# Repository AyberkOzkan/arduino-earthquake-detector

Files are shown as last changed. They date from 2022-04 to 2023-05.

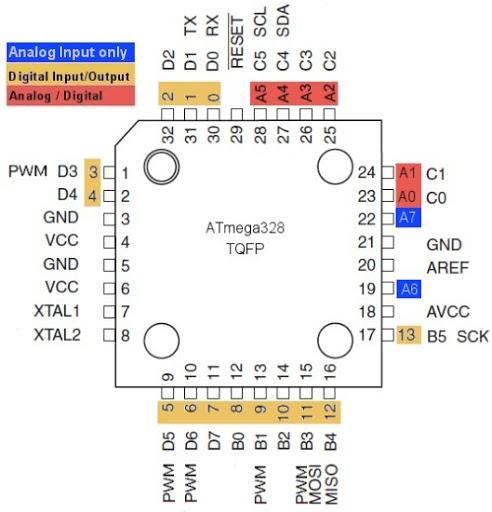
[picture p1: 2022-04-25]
Özel Arduino Nano Tasarımı/Arduino ATmega328 Pinout.jpg

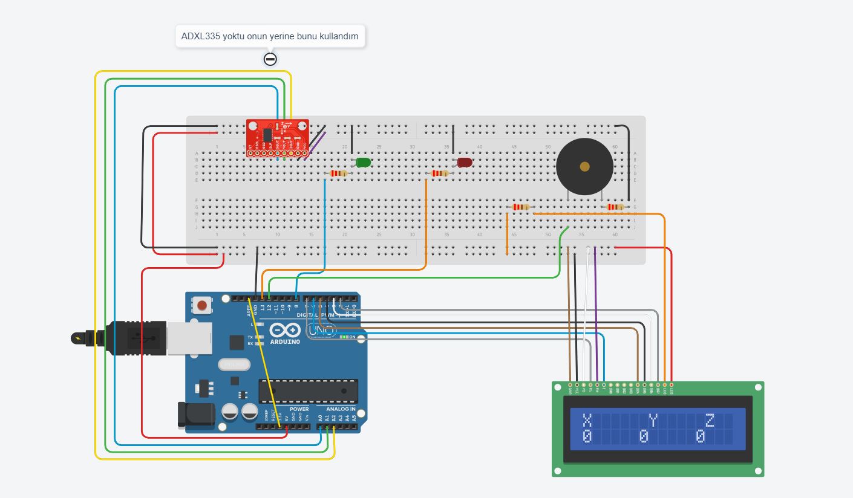
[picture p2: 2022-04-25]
TinkerCad Bağlantı Şeması.JPG

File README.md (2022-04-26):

# Arduino Earthquake Detector

### What I did use?
- Arduino Nano (Personalized and Redesigned) and Arduino UNO
- ADXL335 3 Axis Accelerometer
- 2x16 LCD Display
- Led (Red and Green)
- Resistors
- Buzzer
- Jumper Cables
- Arduino IDE
- Altium Designer
- Processing 3
- Tinkercad

## Tinkercad Connection Diagram


```Bash
The sensitivity was very low when it was first turned on. In order to increase its sensitivity, 
the AREF pin is connected to the 3V3 pin and the analogue inputs are set to 3.3V instead of 5V. 
This made the ADXL335 work more smoothly.
```
## Conclusion and Discussion
> I had the opportunity to test the project with artificial vibrations and real earthquakes and the expected results were obtained. Thanks to its small design, it adapts well to the place where it is intended to be mounted. The fact that this place is the columns of the building will enable the sensor to work more accurately. In addition, with Arduino, we can adjust how natural gas, water or other smart home systems of important systems should behave in case of an earthquake. Vibration waves can be watched and recorded live on Processing with the help of a computer.
> I designed an additional circuit to further increase its sensitivity.
```Bash
The main logic of this circuit was this: to amplify only the useful part of the signal without amplifying harmful noise.
```

>To do this, the instrumental operational amplifier i.e. OPAMP, connected in differential mode, OP07 IC can be used as an example. It can be used in any OPAMP IC. Using the potentiometer, we must set the voltage V2 to be slightly lower than V1 and set the utility signal with a second potentiometer.
>The formula for the amplification coefficient is 
<p align = "center">Vout = (V1-V2) * K<p/>
<p align = "center">K = 1 + 100 / P2 (kOhm)<p/>

> This amplified signal must be connected to the analogue input of an Arduino microcontroller via a 1k resistor. 
> To amplify the ADXL335's three outputs, we will need to use three identical amplifiers for each axis (x, y and z) separately.

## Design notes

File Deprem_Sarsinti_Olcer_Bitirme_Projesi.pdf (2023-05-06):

T.C.

### FIRAT ÜNİVERSİTESİ

### TEKNOLOJİ FAKÜLTESİ

### ELEKTRİK-ELEKTRONİK MÜHENDİSLİĞİ BÖLÜMÜ

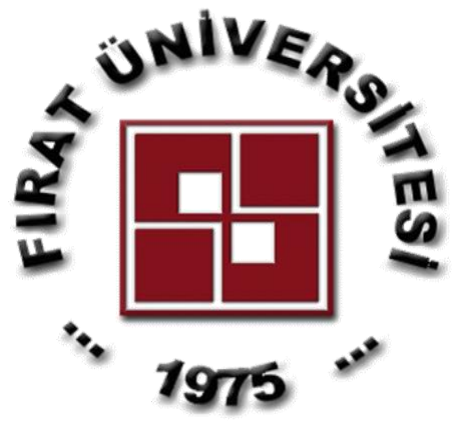
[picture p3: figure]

## ARDUİNO İLE DEPREM VE SARSINTI ALGILAYICI

### BİTİRME PROJESİ

### Hazırlayan

16503050 KENAN AYBERK ÖZKAN

### Bitirme Yöneticisi

DOÇ.DR. ÇETİN GENÇER

ELÂZIĞ 2020

T.C.

FIRAT ÜNİVERSİTESİ

TEKNOLOJİ FAKÜLTESİ

ELEKTRİK-ELEKTRONİK MÜHENDİSLİĞİ BÖLÜMÜ

## ARDUİNO İLE DEPREM VE SARSINTI ALGILAYICI

BİTİRME PROJESİ

Hazırlayan

16503050 KENAN AYBERK ÖZKAN

Bitirme Yöneticisi

DOÇ.DR. ÇETİN GENÇER

Bu tez, | tarihinde aşağıda belirtilen jüri tarafından oybirliği

/oyçokluğu ile başarılı / başarısız olarak değerlendirilmiştir.

Danışman:

Üye:

Üye:

ELÂZIĞ 2020

I

### ÖNSÖZ

“Arduino ile deprem ve sarsıntı algılayıcı” projesi Fırat Üniversitesi Elektrik-

Elektronik Mühendisliği Bölümü Bitirme Projesi (EET437) dersi için DOÇ.DR. ÇETİN

GENÇER yardımıyla hazırlanmıştır.

Bu projede, ADXL335 kullanılarak Arduino üzerinden depremlerin veya sarsıntıların

ölçülmesi ve veri haline getirilmesi sağlanmıştır.

Bu proje kapsamında proje seçiminden sonuna kadar bizlere yardımcı olan,

sorularımızı öğretici bir şekilde anlatan ve edindiği bilgi ve tecrübeleri bize aktaran DOÇ.DR. ÇETİN GENÇER hocama teşekkür ederim.

II

İÇİNDEKİLER

ÖNSÖZ | I
İÇİNDEKİLER | II
ŞEKİLLER DİZİNİ | III

III

Proje Çalışma Kodları | 25
Arduino IDE Kodları | 25
Processing 3 IDE Kodları | 30

ŞEKİLLER DİZİNİ
Şekil 2.1 Arduino Nano | 6
Şekil 2.2 Arduino Nano Giriş/Çıkışlar | 8
Şekil 2.3 Altium Designer | 9
Şekil 2.4 ADXL 335 Pin bağlantı şeması | 13
Şekil 2.5 ADXL335 Acceloremeter Modülü | 13
Şekil 2.6 2x16 LCD Display | 14
Şekil 2.7 Buzzer | 15
Şekil 2.8 Kırmızı ve Yeşil LED | 16
Şekil 2.9 Jumper Kablo | 17
Şekil 2.10 Processing | 17
Şekil 2.11 Sismografın Anlık Görüntüsü | 18
Şekil 3.1 Şematik Tasarım | 19
Şekil 3.2 4 Katmanlı PCB Tasarım ve 3D Görüntüsü | 20
Şekil 4.1 TinkerCad Bağlantı Şeması | 21
Şekil 4.2 Devrenin Breadboard Bağlantısı | 22

### 1. GİRİŞ

Deprem sensörleri sismik hareketler algıladığında uyarı sağlamak ve binalardaki bazı

sistemleri kesmek amacıyla yani acil otomasyon sistemi olarak kullanılır. Deprem dalgaları

mekanik dalgalardır ve ses dalgaları ile aynıdır. P (Primary) ve S (Secondary) olmak üzere iki

türlü dalgaya sahiptir. P dalgası hızlı ve sesle gelen bir dalga olduğu için deprem sensörlerinin ilk algıladıkları yıkıcı etkisinin az olan dalgalardır. (1) İnsanların tedbir alabileceği zaman bu

dalganın gerçekleştiği andır. Deprem sensörleri bu anda devreye girerek sesli ve görsel uyarı

vermektedir.

İlk sismoskop M.S. 132’de Zhang Heng tarafından icat edilmiştir. Heng’in sismografı,

bakırdan yapılmış büyük bir vazoya benzemekteydi. Cihazın çevresinde 8 adet metal ejderha

kafası vardı ve her ejderhanın ağzına birer bakır top yerleştirilmişti. Ejderhalar; Kuzey,

Güney, Doğu, Batı ve 4 ara yönü temsil ediyordu. Her ejderhanın altında ise ağızları açık

durumda 8 metal kurbağa vardı. Deprem olunca; kabın içindeki mekanizma sayesinde,

sarsıntının geldiği yöndeki ejderhanın ağzındaki bakır top alttaki kurbağanın ağzına

düşmekteydi. Böylece depremin hangi kentte olduğu belirlenebilmekteydi. (2)

Projede rasathanelerde ölçüm için kullanılan sismograf cihazlarındaki akselerometre

ile birlikte Arduino kodlanarak, evlerimizde kullanabileceğimiz daha küçük ve hassasiyeti

daha iyi bir sensör tasarlanmıştır.

### 2. KULLANILAN MALZEMELER VE PROGRAMLAR

-Arduino Nano (Kişiselleştirilmiş ve yeniden tasarlanmış)

-ADXL335 3 Axis Accelerometer

-2x16 LCD Display

-Led (Kırmızı ve yeşil)

-Dirençler

-Buzzer

-Jumper kablolar

-Arduino IDE

-Altium Designer

-Processing 3

-Tinkercad

### 2.1. Arduino

Arduino, üzerinde Atmel mikrokontrolörler bulunan açık kaynak kodlu bir

donanımdır. Yazılım bilgilerinin yanı sıra, tasarım bilgileri de kullanıcının hizmetine

sunulmuştur. PCB baskı devreleri, devre şemaları, yerleşim planları ve üzerindeki

programlanabilir elemanların kodları bütün detayları ile kullanıcının kullanımına rahatça

ulaşabileceği bir şekilde açılmıştır. Kullanıcı isterse hazır olarak alabileceği gibi, aynısını

kendisi de gerçekleştirebilir. Arduino geliştirme kartı üzerindeki mikrokontrolör (AtmegaXX)

Arduino programlama dili ile programlanır ve bu program Processing tabanlı Arduino

Yazılım Geliştirme Ortamı (IDE) yardımı ile karta yüklenir.

Yazılım Geliştirme Ortamı (IDE) internet üzerinden ücretsiz olarak bilgisayara

indirilebilir. (3) Programlama için temel C dili kullanılır. Arduino’yu ön plana çıkaran en

önemli özelliği yazılımının kolay ve sade olmasıdır. Ayrıca kullanıcıya uygulama

gerçekleştirmesi için diğer çevre birimleriyle (kristal, güç kaynağı, programlama cihazı)

uğraşmama imkânı sunar. Programlama cihazına ihtiyaç duymamasının nedeni; ürün,

bootloader programı mikro denetleyicinin içine atılmış şekilde gelmektedir.

Arduino’nun en güçlü özelliklerinden biri de genişletilebilir bir kütüphane sistemine

sahip olmasıdır. Bu kütüphaneler sayesinde birçok işlem ve çevrebirimi haberleşmesi

kolaylıkla gerçekleştirilebilir. Ayrıca yeni çevrebirimleri için yazılan kütüphaneler kolaylıkla

entegre edilebilir. Bütün bunları göz önünde bulundurduğumuzda çok ileri bir yazılımcı

olmadan birçok uygulamayı Arduino kullanarak gerçekleştirebilmek mümkün olur.

Gerçekleştirilmesi istenen projenin özelliğine göre Arduino’nun birçok çeşidi bulunmaktadır.

Ayrıca bu kartlara uygun şekilde tasarlanmış shield (katman) olarak adlandırılmış kullanım

kolaylığı sağlayan ek donanımlar da üreticinin hizmetine sunulmuştur. (Bluetooth, Wireless,

Ethernet, Motor sürücü katmanları vs.).

### 2.1.1. Arduino Kullanım Avantajları

- Arduino, bir önyükleyiciye (bootloader) sahip olduğundan USB port bağlantısı ile

mikroişlemciye program yükleyebilir. Bu sayede mikroişlemcilerdeki çıkarılıp

takılmalardan kaynaklanan bacak kırılmaları riski ortadan kalkar.

- Arduino programlaması diğer programlamalara göre kolaydır.
- Diğer platformlarla karşılaştırıldığında daha ucuzdur.
- Basit ve açık programlama ortamı sayesinde kolay bir yazılım ortamı sağlar.

### 2.1.2. Arduino Nano

ATmega328 temelli Arduino Nano, breadboard ve farklı platformlar ile beraber

kullanılabilir. Arduino IDE’si üzerinden rahatlıkla programlanabilmektedir. DC güç

beslemesi bulunmamaktadır. Buna karşın USB üzerinden besleme yapılabilir. Bununla

beraber Vin pini üzerinden de 5-12V arası giriş gerilimi uygulanabilir.

Arduino, Processing/Wiring dilini kullanarak çevre elemanları ile temel giriş çıkış

uygulamalarını gerçekleştiren açık kaynaklı fiziksel programlama platformudur. Arduino ile

bağımsız olarak interaktif uygulamalar gerçekleştirilebilirsiniz. Aynı zamanda Arduino’yu

bilgisayar ile Flash, Processing, MaxMSP, C Sharp gibi birçok yazılım üzerinden ya da kendi

yazdığınız yazılımlarla haberleştirerek de kullanabilirsiniz. Açık kaynaklı ara yüz yazılımını

internet sitesinden Windows, Mac OS X ve Linux platformları için indirebilirsiniz.

### 2.1.3. Nano Kartın Pinleri ve Özellikleri

Arduino Nano bir B tipi mini USB kablosu ile bilgisayara bağlanarak çalıştırılabilir ya

da harici bir güç kaynağından beslenebilir. 6 – 20 V aralığında bir harici güç kaynağı pin 30

‘a bağlanabilir ya da 5 V regüle edilmiş bir gerilim ile pin 27’den beslenebilir.

3V3: Bu pin daima 3.3V çıkış vermektedir. Bazı hassas elemanlar 3.3V ile çalışmaktadır.

Nano’nun Pro Miniye bir üstünlüğü de üzerinde hem 5V hem de 3.3V çıkış bulunmasıdır. Pro

Miniler ise iki model olup sadece ya 3.3V ya da 5V verebilmektedir.

+5V/VCC: Bazı modellerde +5V bazılarında VCC yazan bu pin arduino çalıştığı sürece 5V

çıkış vermektedir. Ayrıca sabit 5V çıkış veren güç kaynağımız varsa bu pine bağlayarak

Arduino kartımızı besleyebiliriz. Arduino kartı en fazla 40 mA verebildiği için bu amperden

düşük çalışan led gibi elemanları direkt Arduino’ya bağlayabiliriz. Eğer motorlar gibi daha

fazla akım çeken eleman bağlamak istersek harici olarak motor sürücü kartlar kullanmak

gerekecektir.

VIN/RAW: Bazı modellerde VIN bazılarında RAW yazan bu pin Arduino kartımızı

beslemek için kullanmaktayız. 6-20V arasındaki güç kaynağımızı bu pine bağlayarak

kartımızı çalıştırabiliriz. Bu pine bağlı olan regulatör sayesinde 6-20V arasındaki voltaj 5

volta dönüştürülerek karta verilir. Genelde 9V pil kullandığımız için bu pini sık kullanacağız.

GND: Projelerimizde elektrik akışının tam olabilmesi için neredeyse her eleman ile

GND(GROUND) yani toprak hatlarını birleştirmemiz gerekiyor. Bu Arduino’nun (–) kutuplu

4 ve 29 nolu bacağıdır. Sık kullanıldığı için iki tane GND pini konulmuştur.

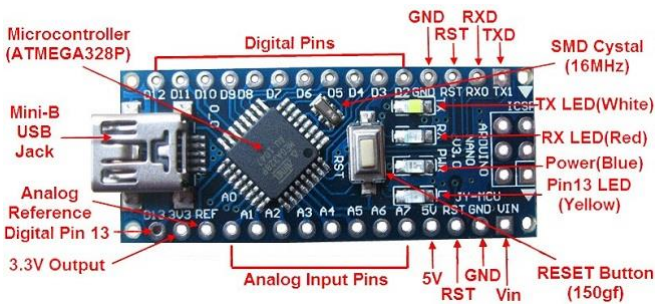
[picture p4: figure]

Şekil 2.1 Arduino Nano

### 2.1.4. Nano Kartın Giriş/Çıkışları

Arduino Nano‘da bulunan 14 tane dijital giriş / çıkış pininin tamamı, pinMode(),

digitalWrite() ve digitalRead() fonksiyonları ile giriş ya da çıkış olarak kullanılabilir. Bu

pinler 5 V ile çalışır. Her pin maksimum 40 mA çekebilir ya da sağlayabilir ve 20-50 KOhm

dahili pull – up dirençleri vardır. Ayrıca bazı pinlerin özel fonksiyonları vardır:

– Serial 0 (RX) ve 1 (TX) : Bu ilk iki pin bilgisayarla TTL seri iletişimin yapıldığı pinlerdir.

RX (receive) alıcı, TX (Transmit) verici bacaktır. Bu iki bacak ayrıca USB bağlantı noktasına

da bağlı olduğu için bu iki bacağı ayrıca kullanmamıza gerek olmayacak.

– Harici kesmeler (2 ve 3) : Bu pinler bir kesmeyi tetiklemek için kullanılabilir.

– PWM: 3, 5, 6, 9, 10, ve 11 : Bu pinler analogWrite () fonksiyonu ile 8-bit PWM sinyali

sağlar.

– SPI: 10 (SS), 11 (MOSI), 12 (MISO), 13 (SCK) : Bu pinler SPI kütüphanesi ile SPI

haberleşmeyi sağlar.

– LED 13: Dijital pin 13’e bağlı bir leddir. Pinin değeri High olduğunda yanar, Low

olduğunda söner.

Arduino Nano‘nun 8 adet analog girişi bulnur, her biri 10 bitlik çözünürlük destekler.

Varsayılan ayarlarda topraktan 5 V a kadar ölçerler. Ancak, AREF pini ve analogReference()

fonksiyonu kullanılarak üst limit ayarlanabilir. Analog pinlerinden 6 ve 7 dijital pin olarak

kullanılabilirler. Ayrıca bazı pinlerin özel fonksiyonları vardır.

– TWI: A4 ya da SDA pini ve A5 ya da SCL pini Wire kütüphanesini kullanarak TWI

haberleşmesini destekler.

– AREF: Bu pin analog girişlerden okuyacağımız voltaj değerini ayarlamak için

kullanılmaktadır. Normalde nalog giriş pinleri 0-5V arasını okumaktadır. Bu aralığı

değiştirmek için AREF pinine okuması istediği voltajı veriyoruz. Analog girişler için referans

voltajıdır. analogReference() fonksiyonu ile kullanılır.

– RESET: Arduino içine yazdığımız yazılımın işlem sırasını en başa alarak programı yeniden başlatır. İçindeki programı silmez. Arduino üzerindeki reset tuşu bu pine bağlıdır. Projelerde

ayrı bir reset tuşu kullanmak istediğimizde bu pin kullanılır.

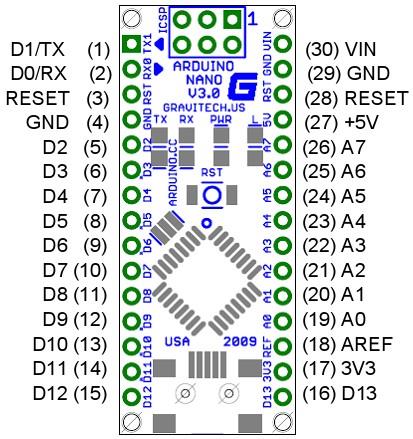
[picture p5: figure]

Şekil 2.2 Arduino Nano Giriş/Çıkışlar

### 2.2. Altium Designer

Avustralyalı yazılım şirketi Protel tarafından geliştirilen bir PCB çizim ve tasarım

programıdır. Elektronik ürün geliştirmek için gereken tüm gereçleri içerisinde barındıran

yazılım entegrasyon programıdır. Altium Designer (4) tek bir uygulama ile tasarımın

konseptten tamamlanmış haline kadar geliştirilmesini sağlar. Donanım, yazılım ve

programlanabilen donanımları birleştirir. Türkiye de piyasa da çok talep gören baskı devre

tasarım programıdır.

PCB, elektronik devrelerin bakır yollar ve komponentleri içerecek şekilde, plakalar üzerinde

işlenmiş halidir. Dolayısı ile program bir elektronik tasarımın temelini oluşturmaktadır.

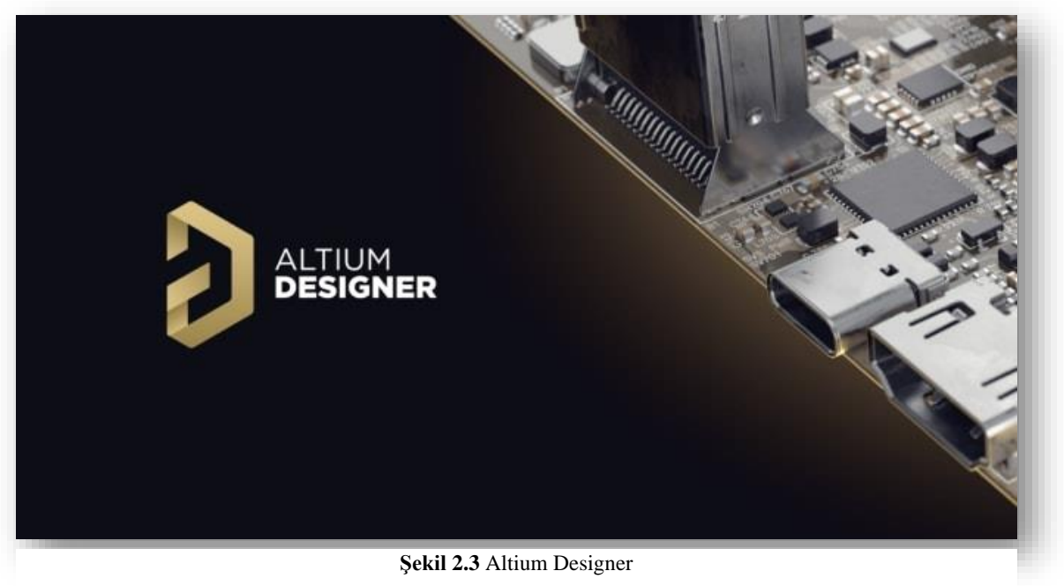
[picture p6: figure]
Şekil 2.3 Altium Designer

Altium Designer programı çok gelişmiş bir hata analiz motoruna sahip. Ayrıca

gelişmiş bir simülasyon motoru sayesinde, devre üzerinde bulunan tüm elemanların zamana

göre değişimini gösteren grafiksel analiz yapabiliyorsunuz. HDL, VHDL, C, XML vb.

gelişmiş birçok programlama alt yapısına sahip olan Altium Designer ile yazacağınız

programları aynı program üzerinde bulunan şematik çizimde deneme şansına sahipsiniz.

Programın bir diğer özelliği de gelişmiş kütüphanesi ve program ile birlikte gelen çok geniş şablon dosyalar bulundurmasıdır. Üzerinde gelen birçok şablonu inceleyerek çizimlerinize

profesyonellik katabilirsiniz. Bazı şablonları ise hiç değiştirmeden olduğu gibi alıp

çizimlerinize ekleme şansına da sahipsiniz. PCB sayfasına baktığımızda, üreticilerinin

söylediğine göre Altium Designer, dünyadaki en iyi otomatik çizim motoruna sahip. Ayrıca

PCB çiziminin en başında koyduğunuz kuralları, çizim sırasında asla ihmal edemiyorsunuz. Örneğin; iki hat arasındaki mesafenin en az 8mil olmasını tanımlamışsanız, çizim sırasında

bir hattın 8mil'den daha yakınına bir hat çizemezsiniz. Bu özelliği sayesinde çizimleri hatasız

bir şekilde sürdürebilirsiniz. Daha öncede söylediğim gibi, karmaşık çizimlerde kart üzerinde

yapılacak en ufak bir yanlış, onca çizimin ve emeğin boşa gitmesi anlamına gelebilir.

Bu yüzden hataları en sonunda ayıklamak yerine, çizim sırasında hata yapmanız

engellenmektedir. Altium Designer'ın bir diğer güzel özelliği de katmanlar arasında çok kolay

bir şekilde dolaşabilirsiniz. 3D özelliği ile kartın gerçeğine birebir uyan üç boyutlu

görüntüsünü görebilir, 3 boyutluyken de katmanlar arasında dolaşıp analizler yapabilirsiniz.

– Bütünleşik Tasarım Ortamı

Şematik çizimi, kolay kullanılan PCB tasarım araçları, gelişmiş 3D görüntüleme,

üretim dosyaları, tasarım kütüphaneleri ve malzeme listesi oluşturma özelliklerini bütünleşik

bir ara yüzde sunmaktadır. Data yönetim sistemi ile kart tasarımını, çevresel birimlere bağlı

ve yalnız önemli olana odaklanarak gerçekleştirmeyi sağlamaktadır.

– Kullanım Kolaylığı

Yeni başlayanlar için tasarımın baştan sona uygulamasını sağlayan dokümantasyonlar içermektedir. İleri düzey özel konulara yönelik eğitim ve videolara erişimin yanı sıra ürünün

web sitesinde bulunan forumlar aracılığıyla ve program kullanımı sırasında etkileşimli yardım

fonksiyonları ile tasarım boyunca kullanıcıya rehberlik etmektedir.

– Akıllı Tasarım Yönetimi

Tasarım ekiplerinin aynı proje üzerinde eş zamanlı çalışma imkanını sağlamaktadır.

Tek merkezli kütüphane yönetimi sayesinde proje ve komponentlerin yaşam döngüsünü

oluşturma ve tekrar kullanabilme; tasarımların varyasyonlarını oluşturma ve üretim

dosyalarının da bu değişikliklere göre elde edilmesini sağlamaktadır.

Tüm ekibin kullandığı Altium Designer versiyonun tek merkezden güncelleştirilme ve

kurulum işlemlerini gerçekleştirmektedir.

– Gerçek Zamanlı Tedarikçi Erişimi

Kart tasarımı süreci boyunca gerçek zamanlı maliyet tahmininin yanı sıra,

tedarikçilerin verilerine ulaşarak, uygun parça seçimine olanak sağlamaktadır.

– Mekanik – Elektronik Tasarım Bütünlüğü

Üç boyutlu görüntüleme özelliği ile PCB’nin gerçeğe yakın ve 2D/3D görüntü

ayarlarına ulaşarak mekanik ver üzerinden “clearance” kontrolü yapmaktadır. Genel olarak

kullanılan Dxf, Step, Parasolid vb. mekanik uzantılarda dosya alma ve aktarma imkânı

vermektedir.

– Geliştirilmiş Dokümantasyon Yetenekleri

Üretim aşamasında kolaylık sağlayacak PCB dokümantasyon yöntemleri

bulunmaktadır. Başka bir programa ihtiyaç duymadan Altium Designer yeteneklerini kullanarak tüm üretim dosyaları elde edilebilmektedir. Üretim öncesinde sunum niteliği

taşıyan ve katı model görüntüsü içeren ön izleme dokümantasyonları oluşturabilmekte, güncel

ürün maliyeti elde edebilmekte ve üretim prosesinin tek dosya içerisinde özetleyebilmektedir.

– Dosya Aktarma ve Alma

Bilgisayar destekli bilinen birçok elektronik devre tasarım araçlarında oluşturulmuş

tasarımları ve kütüphaneleri, desteklenen versiyonlar dahilinde program içerisine alma ve

programdan aktarma desteğini sunmaktadır.

– Simülasyon Özelliği

Analog simülasyon imkânı sunarak istenilen noktalardan voltaj, güç, akım vb. değerler

okunabilmektedir. Osiloskop verilerine benzer dalga formlarını ve AC, DC sinyal analiz eğrilerini çizdirilebilmektedir. Üçüncü parti yazılımlar ile iş birliği sağlayarak işlemci

simülasyonlarını elde etme imkânı sağlamaktadır.

– Katı-Esnek PCB Tasarımı

Katı ve katı-esnek PCB tasarımların oluşturabilmenin yanı sıra bu tasarımların 2D ve

3D görüntülenmesi imkânı sunmaktadır. Esnek yapılar bulunduran tasarımların katlanmış ve

katlanmamış hallerini görüntüleme ve çıktısını alma işlemleri gerçekleştirilebilmektedir.

Mekanik tasarım programlarına veri aktarımı sağlayarak, oluşturulan tasarımın en iyi şekilde

sonlandırılmasında yardımcı olmaktadır. Katı ve katı-esnek PCB tasarım yetenekleri

sayesinde aynı kart üzerinde farklı katman yapısı oluşturulabilmekte ve iç katmanlara

komponent yerleşimine olanak vermektedir.

– Hiyerarşik Tasarım Yapısı

Karmaşık tasarımların okunurluğunu kolaylaştırmak için farklı şematik dosyalarını

bağlantıları ile beraber bir üst şematik dosyasına linkleyerek, kolayca takip edilebilir proje

taslağına çevirme imkânı vermektedir. Tasarımlarda tekrar eden bölümleri, bloklar haline

getirerek ve tek bir blok referans alınarak yerleştirme ve yollandırma işlemlerinin sürelerini

kısaltmaktadır.

– Güç Dağılım Analizi

Devre üzerinde belirlenen bileşenler veya bileşenler ile besleme kaynağı arasında

bulunan bağlantı yolları üzerindeki voltaj düşümü ve akım yoğunluğunu göstermektedir.

Belirlenen hat boyunca katmanlar arasındaki kayıpları veya akım yoğunluğunu 2D/3D

görüntüleme sistemi sayesinde görselleştirerek, kart üzerindeki sorun oluşturabilecek

alanların tespitine olanak sağlamaktadır.

### 2.3. ADXL335 3 Axis Accelerometer

İvmeölçer, ivme kuvvetini ölçen elektromekanik bir cihazdır. Sadece yerçekimi

nedeniyle, yani g kuvveti ile ivmeyi gösterir. İvmeyi g birimi cinsinden ölçer. Bu İvmeölçer

modülü, X, Y ve Z ivmelenmesini analog girişlerden voltaj değerine dönüştürerek veri

üretmektedir. ADXL335 üç eksenli analog ivmeölçer entegre bir devredir. Yerçekimine bağlı

ivme miktarını ölçerek bulunduğu yere göre eğildiği açıyı bulabilir. Dinamik ivmelenme

miktarını algılayarak, cihazın ne kadar hızlı ve hangi yönde hareket ettiğini bulabilir. İvmeölçer, 3 analog giriş pin kullanarak bir mikro denetleyici ile arabirim oluşturmak çok

kolaydır. PIC veya AVR gibi diğer çoğu mikro denetleyici ile kullanılabilir.

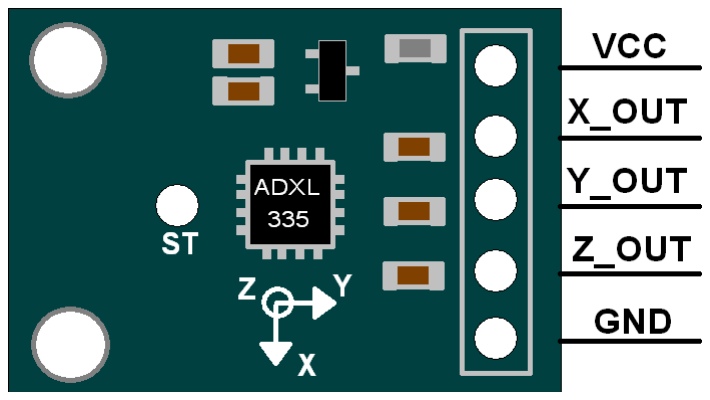
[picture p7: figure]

VCC: Giriş pini.

X_OUT: X ekseni analog çıkışı.

Y_OUT: Y ekseni analog çıkışı.

Z_OUT: Z ekseni analog çıkışı.

GND: Toprak.

ST: Self-Test.

X, Y, Z değerlerini kullanarak eğim hesaplayabiliriz. Ayrıca X, Y ve Z eksenine göre açıları

hesaplayabiliriz. Bu yüzden önce 10 bitlik ADC değerlerini g birimine çevirmemiz gerekiyor.

ADXL335 veri sayfasına göre 0g'de maksimum gerilim seviyesi 1.65V ve hassasiyet ölçek

faktörü 330mV / g'dir. (5)

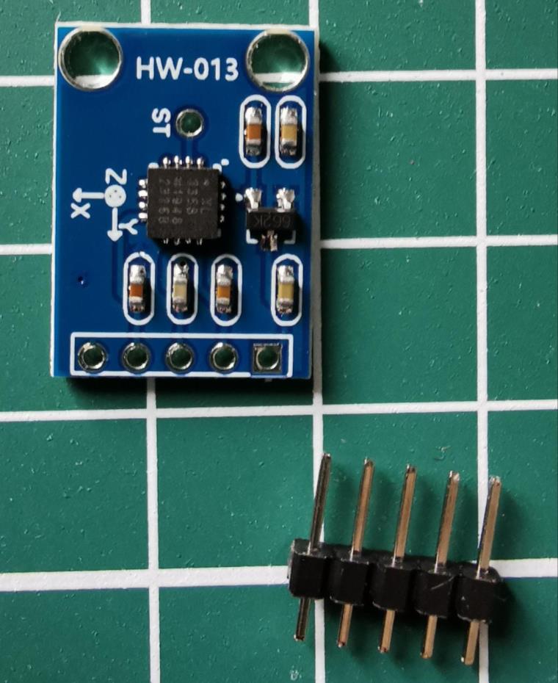
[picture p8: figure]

Şekil 2.5 ADXL335 Acceloremeter Modülü

Şekil 2.4 ADXL 335 Pin bağlantı şeması

Denklem 2.1

Denklem 2.1 bize X, Y ve Z eksenleri için g birimi cinsinden ivme değerlerini şu şekilde

verir:

Axout = (((X ekseni ADC değeri * Vref) / 1024) - 1.65) / 0.330

Ayout = (((Y ekseni ADC değeri * Vref) / 1024) - 1.65) / 0.330

Azout = (((Z ekseni ADC değeri * Vref) / 1024) - 1.65) / 0.330

### 2.4. LCD Display

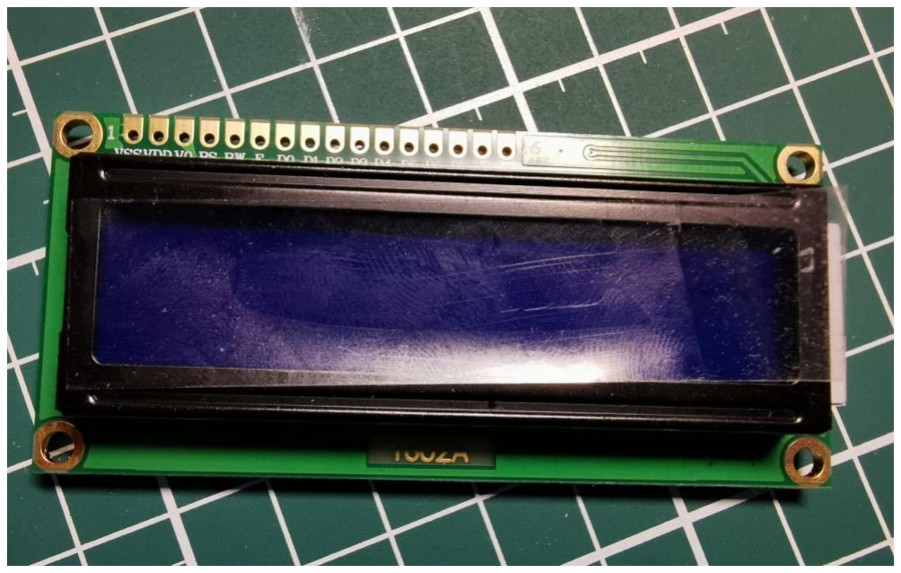
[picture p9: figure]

Şekil 2.6 2x16 LCD Display

2x16 LCD Display 2 satır 16 sütun, bağlantı için 16 adet pin bulunmaktadır. Bazı

ekranlarda arka aydınlatma ışığı bulunmadığından 14 adet pin yer almaktadır. (6) 15 ve 16

numaralı pinler ekran aydınlatması bulunan ekranlarda ışığı yakmak için kullanılır.

Diğer bağlantılar ise şu şekildedir:

- VSS Girişi: GND girişidir. Negatif gerilim bağlanır.
- VDD (5V) Girişi: 5 volt pozitif gerilim bağlanır.
- V0 Girişi: Ekrandaki yazının netliğini ayarlamak için kullanılan voltaj girişidir.
- RS (Register Select): LCD ekranın ne yapacağını, register da bir değer olup olmadığını

kontrol eder.

- R/W (Read/Write): Pinlerin modlarını okuma veya yazma olarak değiştirmek için

kullanılır.

- E (Enable): Pinleri okuma modunda aktif hale getirir.
- D0…D7: Bit bit aldığı değerleri okur. Buradan ekrana yazdırılacak yazılar bit bit

gönderilir. LCD de okur.

- A(Anot) ve K(Katot): Sonda bulunan bu iki girişe + ve – olmak üzere voltaj uygulanır.

Bu sayede LCD’nin arka plan ışığı yanar.

### 2.5. Buzzer

Buzzer; mekanik, elektromekanik ya da piezoelektrik prensiplerine bağlı olarak çalışan

işitsel ikaz cihazı çeşididir. Kullanım alanları oldukça fazla olan buzzerlar, genel itibarıyla

piezoelektrik prensibiyle çalışmaktadırlar. Buzzerlar, kullanım alanlarına da bağlı olarak

alarm, zamanlayıcı, onaylama cevap ikazı gibi işlevlerde kullanılabilmektedirler. (7)

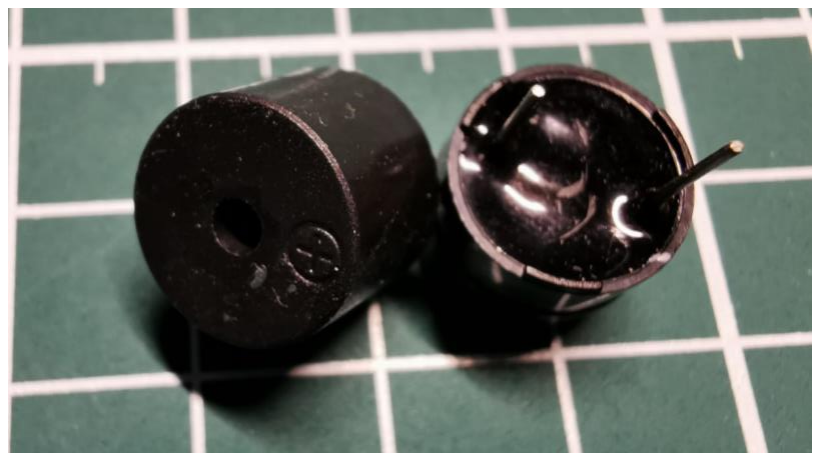
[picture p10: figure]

Şekil 2.7 Buzzer

### 2.6. LED

LED ("Light Emitting Diode", Işık Yayan Diyot), yarı-iletken, diyot temelli, ışık

yayan bir elektronik devre elemanıdır.

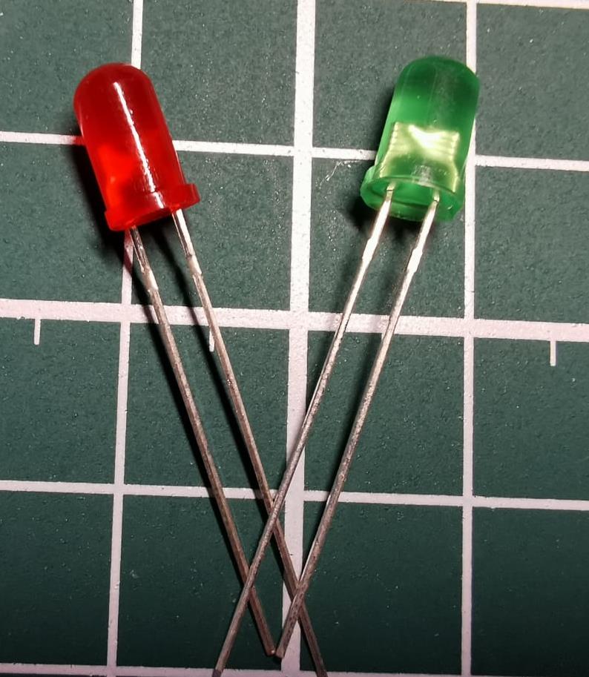
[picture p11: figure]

Şekil 2.8 Kırmızı ve Yeşil LED

### 2.7. Jumper Kablolar

Birçok test projesinde, daha kolay ve daha hızlı işlem yapabilmek için tasarlanmış bir

üründür. Kısaca bir çeşit bağlantı kabloları diyebiliriz. Breadbord ve Arduino arasında

bağlantı kurmak için oldukça kullanışlıdır. Uçlarında erkek ve dişi girişlerin bulunmasına

göre 3 çeşit jumper kablo bulunmaktadır.

-Erkek Erkek

-Erkek Dişi

-Dişi Dişi

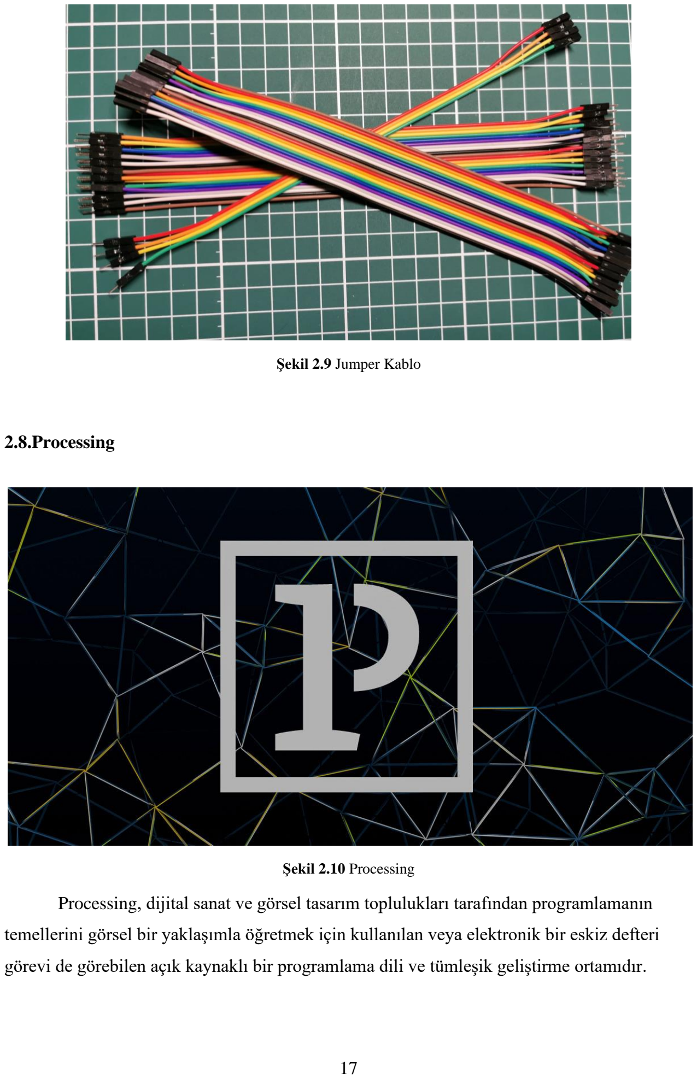
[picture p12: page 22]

Şekil 2.9 Jumper Kablo

2.8.Processing

Şekil 2.10 Processing

Processing, dijital sanat ve görsel tasarım toplulukları tarafından programlamanın

temellerini görsel bir yaklaşımla öğretmek için kullanılan veya elektronik bir eskiz defteri

görevi de görebilen açık kaynaklı bir programlama dili ve tümleşik geliştirme ortamıdır.

2001 yılında Casey Reas ve Benjamin Fry tarafından başlatılan proje Java üzerine kurulmuş

olup daha basit bir grafik programlama modeli ve sözdizimine sahiptir. (8)

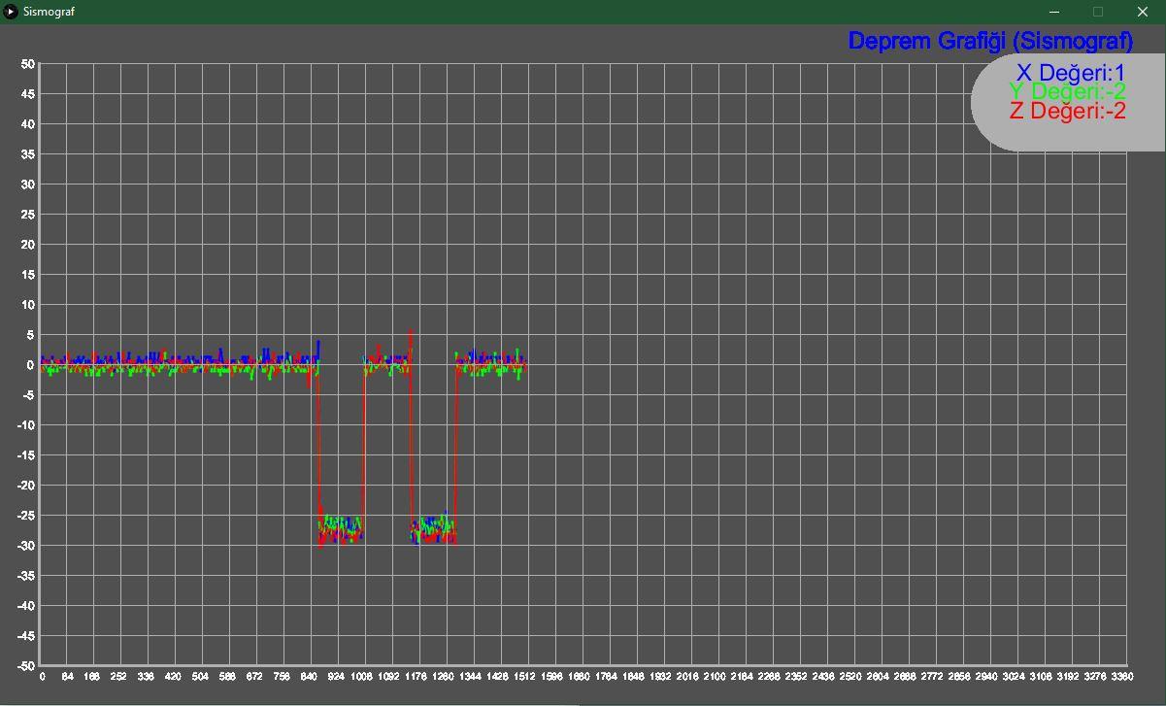
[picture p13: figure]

Şekil 2.11 Sismografın Anlık Görüntüsü

### 2.9. TinkerCad

Tinkercad, basitliği ve kullanım kolaylığı ile bilinen bir web tarayıcısında çalışan

ücretsiz, çevrimiçi bir 3B modelleme programıdır. Dünyanın her yerinden insanların

düşünmesine ve yaratmasına yardımcı olan ücretsiz bir çevrimiçi yazılım araçları

koleksiyonudur. 3D tasarım, mühendislik ve eğlence yazılımlarında lider olan Autodesk için

ideal bir giriş yapıyor. 2011'de kullanıma sunulduğundan bu yana, okullarda yapıcı katı

geometriye giriş düzeyinde bir giriş olmasının yanı sıra 3D baskı için modeller oluşturmak

için popüler bir platform haline geldi. (9)

### 3. ARDUİNO NANO’NUN YENİDEN TASARLANMASI

Bu projede kullanılacak olan Arduino Nano’yu boyut olarak daha az yer kaplaması

için küçültülmüş, yenileştirilmiş ve projenin ihtiyaçları doğrultusunda tasarlanmıştır. Altium

Designer kullanarak şematik ve 4 katmanlı PCB tasarımı yapılmıştır.

### 3.1 Şematik Tasarım

Sadece Mikrokontrolör değiştirilmeden diğer komponentler değiştirilerek tasarım

güncellenmiştir. Komponentlerin seçiminde kalite, ucuz ve kolay bulunabilmesi

amaçlanmıştır.

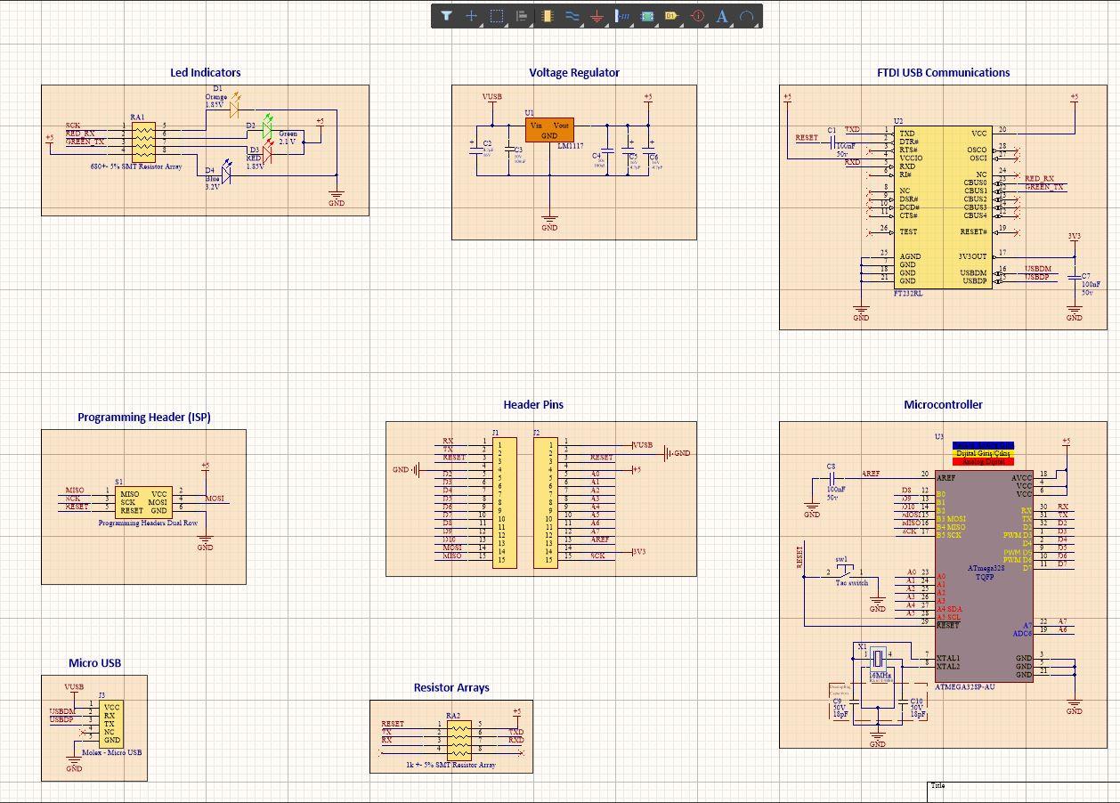
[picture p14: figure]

Şekil 3.1 Şematik Tasarım

### 3.2 PCB Tasarım

PCB Tasarımında orijinal Arduino Nano’ya nazaran daha az yer kullanılmış ve bakır

yollar daha kısaltılmıştır. Ayrıca ısınma sorunu olan yerlere soğutucu Via’lar eklenmiştir. 4

katmanlı olmasına rağmen daha az Via kullanılmıştır. Gürültüyü azaltmak için kartın köşeleri orijinaline göre farklı tasarlanmıştır. İleride aşınması muhtemel olan bakır yollar daha kalın

çizilmiştir.

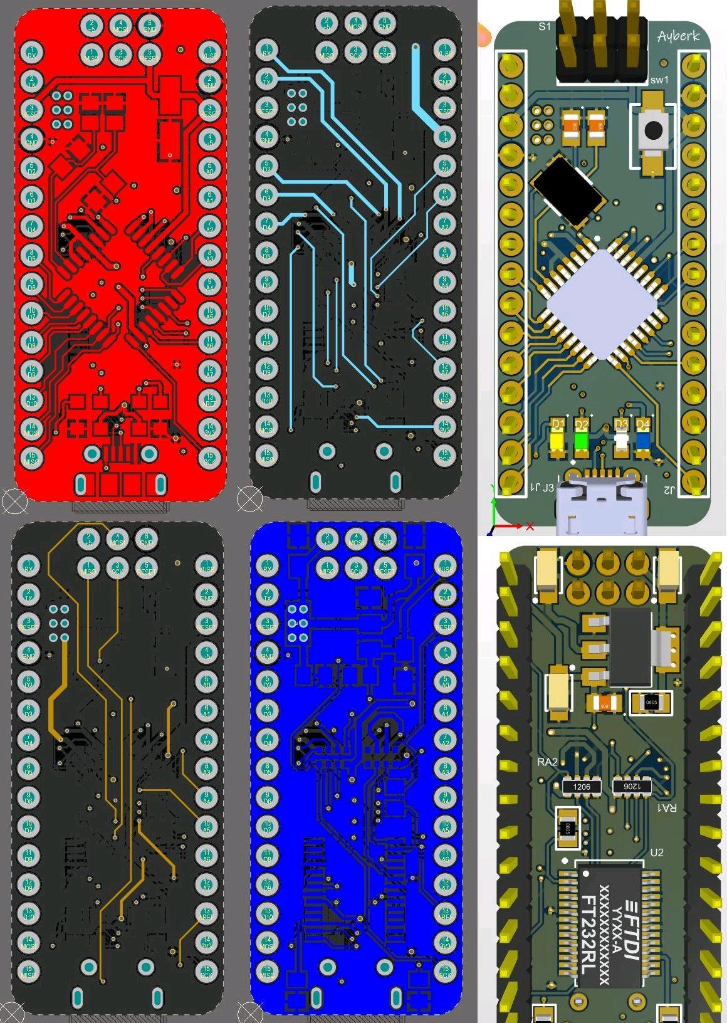
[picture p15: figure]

Şekil 3.2 4 Katmanlı PCB Tasarım ve 3D Görüntüsü

### 4. TİNKERCAD BAĞLANTI ŞEMASI VE İLK TEST AŞAMASI

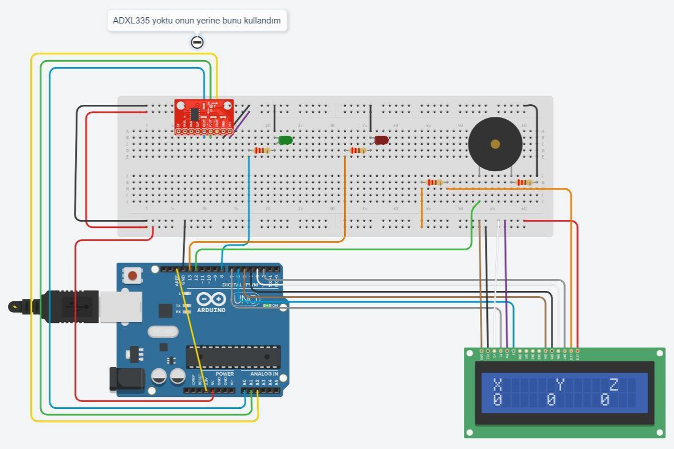
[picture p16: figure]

Şekil 4.1 TinkerCad Bağlantı Şeması

İhtiyaçlar doğrultusunda Arduino Nano baştan tasarlandıktan sonra gerber dosyaları

üreticiye gönderildi. Fakat üretim aşaması yoğun olduğu için gecikme olacağı söylendi. Bu

sırada Arduino Uno kullanılarak program yazılmaya başlanıldı. TinkerCad kullanılarak hızlı

ve kolay bir şekilde bağlantı simülasyonu yapıldı bu sayede gerçek cihazda herhangi bir problemle karşılaşılmadan bağlantıları kolayca yapıldı. İlk çalıştırıldığında hassasiyeti çok

düşük düzeydeydi. Hassasiyetini arttırmak için AREF pini ile 3V3 pini arasında bağlantı

yapılarak analog girişler 5V yerine 3.3V girişe ayarlandı. Buda ADXL335’in daha düzgün

çalışmasını sağlamış oldu.

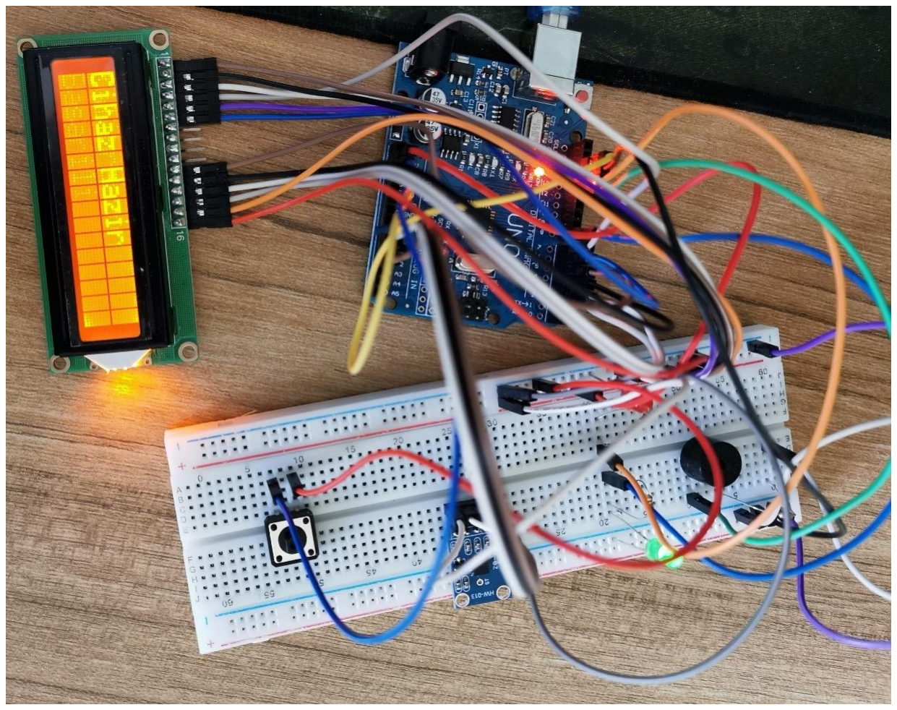
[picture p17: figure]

Şekil 4.2 Devrenin Breadboard Bağlantısı

### 5. SONUÇ VE TARTIŞMA

Projeyi yapay titreşimler ve gerçek deprem ile test etme imkânım oldu ve beklenilen

sonuçlar elde edildi. Tasarımının küçük olması sayesinde monte edilmek istenilen yere gayet

uyum sağlıyor. Bu yerin binanın kolonları olması sensörün daha doğru çalışmasını

sağlayacaktır. Buna ek olarak Arduino ile önemli sistemlerin doğalgaz, su veya akıllı diğer ev

sistemlerinin deprem anında nasıl davranması gerektiğini ayarlayabiliriz. Bir bilgisayar

yardımıyla Processing üzerinden canlı olarak titreşim dalgaları izlenebilir ve bunların kaydı

tutulabilir.

Hassasiyetinin daha da arttırılması için ek bir devre tasarladım. Bu devrenin ana

mantığı şu oldu: Zararlı gürültüyü yükseltmeden sinyalin yalnızca faydalı kısmını

yükseltmek. Bunu yapmak için diferansiyel modunda bağlanan enstrümantal işlemsel

amplifikatör yani OPAMP, OP07 IC örnek olarak kullanılabilir. Herhangi bir OPAMP IC’de kullanılabilir. Potansiyometre kullanarak, V2 voltajını V1'den biraz daha düşük olacak şekilde

ayarlanmalı ve ikinci bir potansiyometre ile faydalı sinyali ayarlamalıyız. Amplifikasyon

katsayısı için formül Vout = (V1-V2) * K'dir, burada K = 1 + 100 / P2 (kOhm). Bu

güçlendirilmiş sinyal, 1k direnç üzerinden bir Arduino mikrodenetleyicisinin analog girişine

bağlanmalı. ADXL335'in üç çıkışını yükseltmek için, her bir eksen (x, y ve z) için ayrı ayrı bu

tür üç özdeş amplifikatör kullanmamız gerekecektir.

Kaynakça

1. Tech, Michigan. What is seismology and what are seismic waves? http://www.geo.mtu.edu/UPSeis/waves.html. [Çevrimiçi]
2. Boğaziçi Üniversitesi, Kandilli Rasathanesi ve Deprem Araştırma Enstitüsü. http://www.koeri.boun.edu.tr/sismo/bilgi/sss_tr.htm#:~:text=İlk%20sismoskop%20M.S.,Chang%20H eng%20tarafından%20icat%20edilmiştir.
3. Arduino. https://www.arduino.cc/en/software. [Çevrimiçi]
4. Altium Designer. https://www.altium.com. [Çevrimiçi]
5. Devices, Analog. https://www.analog.com/media/en/technical-documentation/data-sheets/adxl335.pdf. [Çevrimiçi]
6. İkizoğlu, Kemal. http://blog.ikizoglu.com/2017/10/arduino-2x16-lcd-ekran-kullanimi/. [Çevrimiçi] 30 Ekim 2017.
7. İLX. https://medium.com/@ilxmuhendislik1/buzzer-nedir-nasıl-çalışır-7f902167f595. Medium. [Çevrimiçi]
8. https://en.wikipedia.org/wiki/Processing_(programming_language). [Çevrimiçi]
9. AutoDesk. https://www.tinkercad.com. TinkerCad. [Çevrimiçi]

Proje Çalışma Kodları

Arduino IDE Kodları

#include<LiquidCrystal.h> // LCD kütüphanesi

LiquidCrystal lcd(7,6,5,4,3,2); // LCD bağlantı pinleri

#define buzzer 12 | // Buzzer pin'i seçildi.

#define led 13 | // Led pin'i seçildi.

#define led2 8 | // 2.Led Pini seçildi.(Durum Ledi)

#define x A0 | // Accelerometer'ın X çıkışı Analog olarak tanımlandı.

#define y A1 | // Accelerometer'ın Y çıkışı Analog olarak tanımlandı.

#define z A2 | // Accelerometer'ın Z çıkışı Analog olarak tanımlandı.

/*Değişkenler*/

int xdegeri=0;

int ydegeri=0;

int zdegeri=0;

long Baslat;

int buz=0;

/*Değişmeyen Girdiler*/

#define ornekler 50

#define maxDeg 5 | // max değişmesini istediğin değer limiti

#define minDeg -500 | // min değişmesini istediğin değer limiti

#define buzTime 5000 | // buzzer ötme süresi

void setup()

{

lcd.begin(16,2); | // LCD Başlatılıyor.
analogReference(EXTERNAL); | // Daha iyi sonuçlar alabilmek için AREF girişini

3.3V'a çevirdim. Arduino Uno'da bağlantı yapmayı unutma. **Bu kodu yazmazsan ve

bağlantı yaparsan Arduino'yu yakabilirsin!

Serial.begin(9600); | // Serial bağlantı başlatılıyor.
delay(1000); | // Gecikme

lcd.print("Deprem ");

lcd.setCursor(0,1); | // LCD Karakter ayarlaması için.

lcd.print("Sensoru ");

delay(2000);

lcd.clear(); | // LCD ekranı sil.

lcd.print("Kalibre Ediliyor.....");

lcd.setCursor(0,1);

lcd.print("Bekleyin...");

delay(100);

pinMode(buzzer, OUTPUT); // Takılı kalmasın diye kapalı olduklarından emin

oluyorum.

pinMode(led, OUTPUT);

//pinMode(led2, OUTPUT);

buz=0; | // Buzzer'ın pasif konumda olduğundan emin oluyorum

digitalWrite(buzzer, buz);

digitalWrite(led, buz);

for(int i=0;i<ornekler;i++) // Kalibrasyon için örnek alıyor.

{

xdegeri+=analogRead(x);

ydegeri+=analogRead(y);

zdegeri+=analogRead(z);

}

xdegeri/=ornekler; | // X için ortalama değer alınıyor.
ydegeri/=ornekler; | // Y için ortalama değer alınıyor.
zdegeri/=ornekler; | // Z için ortalama değer alınıyor.

delay(5000);

lcd.clear();

lcd.print("Kalibrasyon ");

lcd.setCursor(0,1);

lcd.print("Basarili");

digitalWrite(led2, HIGH);

delay(1000);

lcd.clear();

lcd.print("Cihaz Hazir");

delay(1000);

lcd.clear();

lcd.print(" X Y Z ");

}

void loop()

{

int deger1=analogRead(x); | // X Çıkışı okunuyor.
int deger2=analogRead(y); | // Y Çıkışı okunuyor.
int deger3=analogRead(z); | // Z Çıkışı okunuyor.
int xDeger=xdegeri-deger1; | // X'teki değişim bulunuyor.
int yDeger=ydegeri-deger2; | // Y'teki değişim bulunuyor.
int zDeger=zdegeri-deger3; | // Z'teki değişim bulunuyor.

/*LCD'de değerlerin gözükmesi için.*/

lcd.setCursor(0,1);

lcd.print(xDeger);

lcd.setCursor(6,1);

lcd.print(yDeger);

lcd.setCursor(12,1);

lcd.print(zDeger);

delay(100);

/* Aralıkların belirlenmesi*/

if(xDeger < minDeg || xDeger > maxDeg || yDeger < minDeg || yDeger > maxDeg ||

zDeger < minDeg || zDeger > maxDeg) //x,y ve z değerlerinin aralıklarındaki değişim

şartları.

{

if(buz == 0)

Baslat=millis(); | // Zamanlayıcı
digitalWrite(led2, LOW); | // Durum Ledinin sönmesi

buz=1; | | // buzzer ve Led'in aktif olması

}

else if(buz == 1) | // Deprem alarmı verildiğinde buzzer'ın aktif olması 1 aktif

0 pasif

{

lcd.setCursor(0,0);

lcd.print("Deprem Alarmi ");

if(millis()>= Baslat+buzTime)

buz=0;

}

else

{

lcd.clear();

lcd.print("X | Y | Z ");
digitalWrite(led2, HIGH); | // Durum Ledi: stabil ve her şey çalışıyorsa aktif.

}

digitalWrite(buzzer, buz); | // buzzer aktif-pasif komutu
digitalWrite(led, buz); | // led aktif-pasif komutu

/*Değerleri serial port'una gönderiyor.*/

Serial.print("x=");

Serial.println(xDeger);

Serial.print("y=");

Serial.println(yDeger);

Serial.print("z=");

Serial.println(zDeger);

Serial.println("_");

}

Processing 3 IDE Kodları

import processing.serial.*;

PFont f6, f8, f12, f10;

PFont f24;

Serial myPort; // Seri bağlantı noktası

int xPos = 0; // Grafiğin yatay konumunu ayarladım.

float y1=0;

float y2=0;

float y3=0;

void setup ()

{

//*Pencere Boyut Ayarı ve Yazı Tipi Boyutu*//

f6 = createFont("Arial", 6, true);

f8 = createFont("Arial", 8, true);

f10 = createFont("Arial", 10, true);

f12 = createFont("Arial", 12, true);

f24 = createFont("Arial", 24, true);

size(1600, 800); //Pencere Boyutu

//*Aktif olan tüm seri bağlantı noktaları*//

println(Serial.list());

myPort = new Serial(this, "COM8", 9600); // Arduino ile bağlantı port'u COM8

println(myPort);

myPort.bufferUntil('\n');

background(80);

}

void draw ()

{

serial ();

}

void serial()

{

String inString = myPort.readStringUntil('_'); // Gelen veriyi porttan okuyor.

if (inString != null)

{

//* 3 eksen için gereken değerlerin elde edilmesi *//

int l1=inString.indexOf("x=")+2;

String temp1=inString.substring(l1, l1+3);

l1=inString.indexOf("y=")+2;

String temp2=inString.substring(l1, l1+3);

l1=inString.indexOf("z=")+2;

String temp3=inString.substring(l1, l1+3);

//* X, Y ve Z değerlerinin grafik ile ölçülendirilmesi *//

float inByte1 = float(temp1+(char)9);

inByte1 = map(inByte1, -80, 80, 0, height-80);

float inByte2 = float(temp2+(char)9);

inByte2 = map(inByte2, -80, 80, 0, height-80);

float inByte3 = float(temp3+(char)9);

inByte3 = map(inByte3, -80, 80, 0, height-80);

float x=map(xPos, 0, 1120, 40, width-40);

//*Grafiği pencerisini çizdirmek için*//

strokeWeight(2);

stroke(175);

Line(0, 0, 0, 100);

textFont(f24);

fill(0, 00, 255);

textAlign(RIGHT);

xmargin("Deprem Grafiği (Sismograf)", 200, 100);

fill(100);

strokeWeight(100);

line(1450, 80, 1600, 80); // Gri Alan

strokeWeight(1);

textAlign(RIGHT);

fill(0, 0, 255);

String temp="X Değeri:"+temp1;

Text(temp, 100, 95);

fill(0, 255, 0);

temp="Y Değeri:"+temp2;

Text(temp, 100, 92);

fill(255, 0, 0);

;

temp="Z Değeri:"+temp3;

Text(temp, 100, 89);

//*X, Y ve Z değerlerini grafik üstünde çizdirme*//

strokeWeight(2);

int shift=40;

stroke(0, 0, 255);

if (y1 == 0)

y1=height-inByte1-shift;

line(x, y1, x+2, height-inByte1-shift) ;

y1=height-inByte1-shift;

stroke(0, 255, 0);

if (y2 == 0)

y2=height-inByte2-shift;

line(x, y2, x+2, height-inByte2-shift) ;

y2=height-inByte2-shift;

stroke(255, 0, 0);

if (y2 == 0)

y3=height-inByte3-shift;

line(x, y3, x+2, height-inByte3-shift) ;

y3=height-inByte3-shift;

xPos+=1;

if (x >= width-30) // Başlangıç noktasına dönüyor...

{

xPos = 0;

background(80);

}

}

}

void Line(int x1, int y1, int x2, int y2)

{

float xx1=map(x1, 0, 100, 40, width-40);

float xx2=map(x2, 0, 100, 40, width-40);

float yy1=map(y1, 0, 100, height-40, 40);

float yy2=map(y2, 0, 100, height-40, 40);

line(xx1, yy1, xx2, yy2);

xx2=map(100, 0, 100, 40, width-40);

yy2=map(0, 0, 100, height-40, 40);

line(xx1, yy1, xx2, yy2);

strokeWeight(1);

for (int i=1; i<21; i++)

{

yy2=map(i*10, 0, 200, height-40, 40);

yy1=yy2;

line(xx1, yy1, xx2, yy2);

}

yy2=map(100, 0, 100, height-40, 40);

yy1=map(0, 0, 100, height-40, 40);

for (int i=1; i<41; i++)

{

xx1=map(i*5, 0, 200, 40, width-40);

xx2=map(i*5, 0, 200, 40, width-40);

line(xx1, yy1, xx2, yy2);

}

textAlign(RIGHT);

// sonuc+=yy1; XXX

fill(255);

strokeWeight(1);

textFont(f12);

for (int i=-10; i<11; i++)

{

String sonuc="";

sonuc+=5*i;

ymargin(sonuc, x1, y1);

y1+=5;

}

x1=0;

y1=0;

strokeWeight(1);

textFont(f10);

for (int i=0; i<41; i++)

{

String sonuc="";

sonuc+=28*3*i;

xmargin(sonuc, x1, y1);

x1+=5;

}

textAlign(RIGHT);

textAlign(RIGHT);

}

void ymargin(String deger, int x1, int y1)

{

float xx1=map(x1, 0, 100, 40, width-40);

float yy1=map(y1, 0, 100, height-40, 40);

text(deger, xx1-5, yy1+5);

}

void xmargin(String deger, int x1, int y1)

{

float xx1=map(x1, 0, 200, 40, width-40);

float yy1=map(y1, 0, 100, height-25, 25);

text(deger, xx1+7, yy1);

}

void Text(String deger, int x1, int y1)

{

float xx1=map(x1, 0, 100, 40, width-40);

float yy1=map(y1, 0, 100, height-25, 25);

text(deger, xx1, yy1);

}

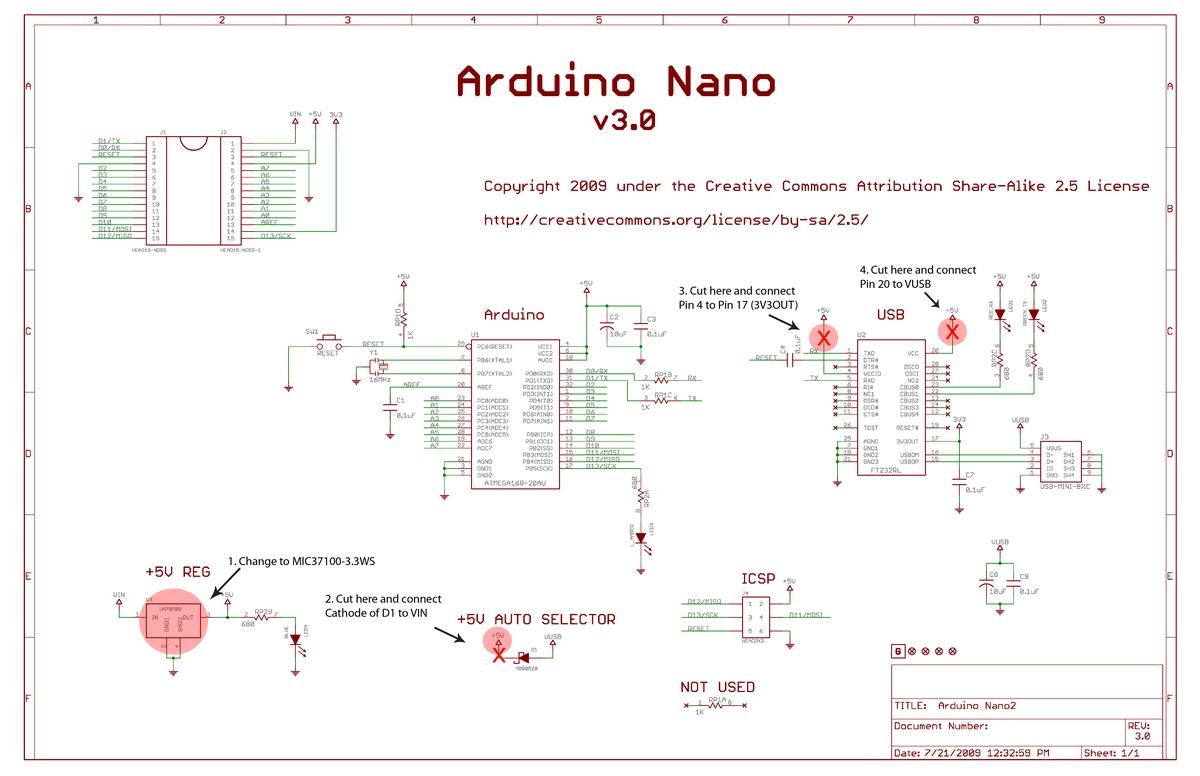
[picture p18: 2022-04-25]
Özel Arduino Nano Tasarımı/8fd06-arduinonano-3.3.png

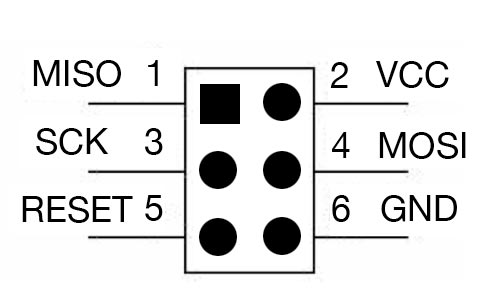
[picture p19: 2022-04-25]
Özel Arduino Nano Tasarımı/avrispmkII-pin-out.jpg

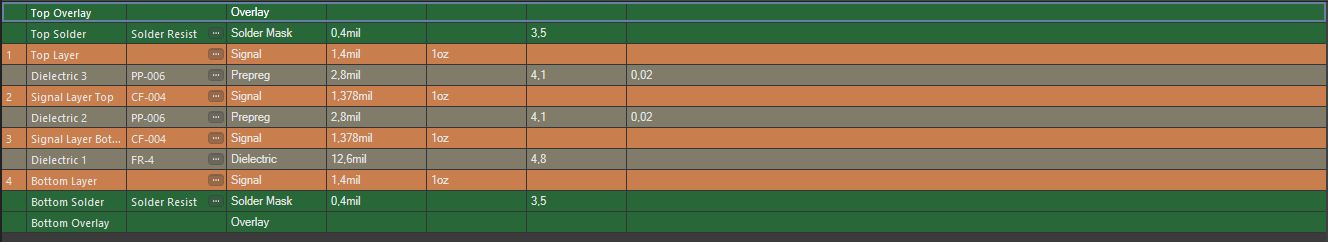
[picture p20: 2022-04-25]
Özel Arduino Nano Tasarımı/LayerStackManager.JPG

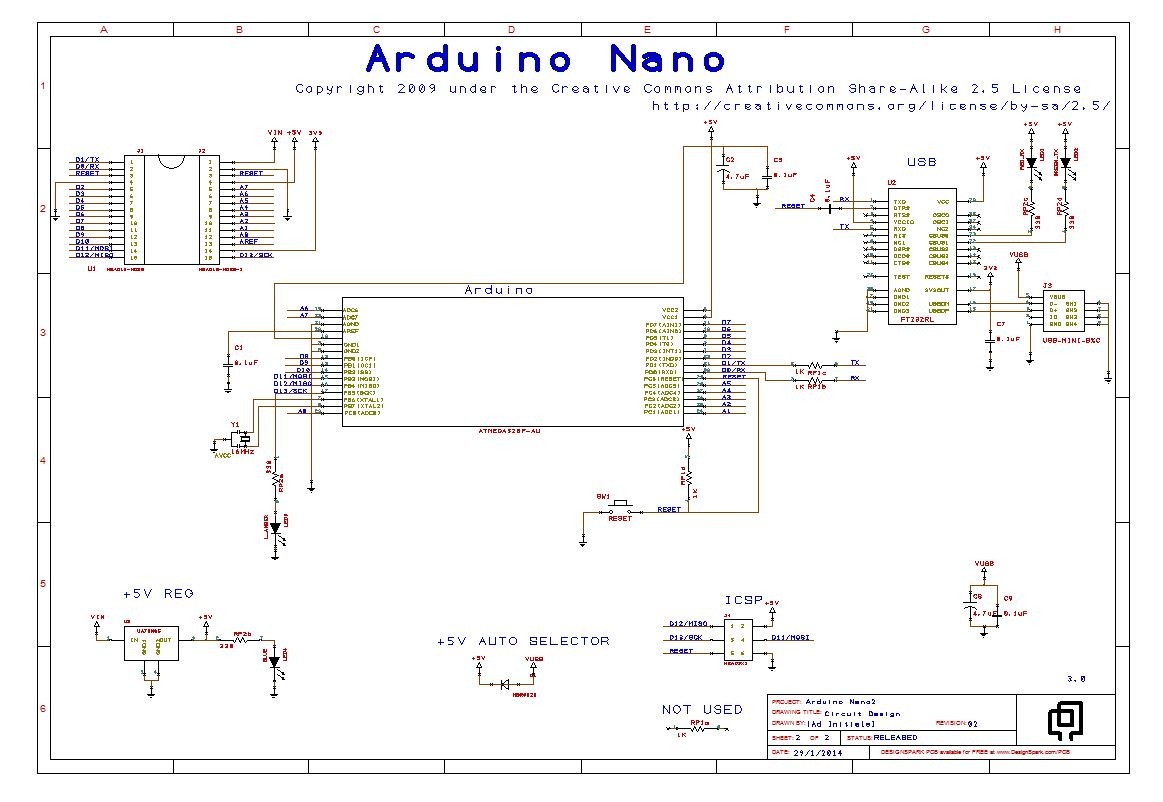
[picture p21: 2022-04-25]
Özel Arduino Nano Tasarımı/Örnek şema.jpg

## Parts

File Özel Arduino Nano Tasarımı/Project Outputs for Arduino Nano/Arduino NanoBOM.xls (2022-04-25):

Comment | Description | Designator | Footprint | LibRef | Quantity
100nF | None polar capacitor | C1, C4, C7, C8 | MY_0805 | Cap ceramic | 4
Capacitor SMT Tantalum | Capacitor,tantalum,SMT,16V,4.7uF,10%,A-case | C2, C5, C6 | CASE A - 3216X18 | 4.7µF Tant RS 496-3545 | 3
100nF Ceramic Multilayer Capacitor_1 | AVX 0805 Standard 100nF Ceramic Multilayer Capacitor, 50 V dc X7R Dielectric ±10% SMD | C3 | CAPCP2012X09N | 100nF Ceramic Multilayer Capacitor_1 | 1
C0805C180J5GACTU | 18pF Ceramic Multilayer Capacitor, 50 V dc C0G Dielectric ±5% SMD | C9, C10 | CAPCP2012X09N | 18pF Ceramic Multilayer Capacitor, 50 V dc C0G Dielectric ±5% SMD | 2
Kingbright Orange LED, 200 mcd 120 ° 0805 | Kingbright Orange LED, 200 mcd 120 ° 0805 | D1 | LED1913X12NYEL/ORANGE | Kingbright Orange LED, 200 mcd 120 ° 0805 | 1
Kingbright Green LED, 70 mcd 120 ° 0805 | Kingbright Green LED, 70 mcd 120 ° 0805 | D2 | LED1913X12NGREEN | Kingbright Green LED, 70 mcd 120 ° 0805 | 1
Kingbright Red LED, 100 mcd 120 ° 0805 | Kingbright Red LED, 100 mcd 120 ° 0805 | D3 | LED1913X12NRED | Kingbright Red LED, 100 mcd 120 ° 0805 | 1
Kingbright Blue LED, 60 mcd 120 ° 0805 | Kingbright Blue LED, 60 mcd 120 ° 0805 | D4 | LED1913X12NBLUE | Kingbright Blue LED, 60 mcd 120 ° 0805 | 1
connector;str header;single row;.1 cont centers;.095 tail;gold or gtx;36 contact | connector;str header;single row;.1 cont centers;.095 tail;gold or gtx;36 contact | J1, J2 | Header | Single row; PCB headers | 2
Molex - Micro USB | Molex USB Connector, SMT, Socket B, Solder, Right Angle | J3 | MOLEX_1050170001 | Molex - Micro USB Connector 30V, 1.8A | 1
680+- 5% SMT Resistor Array | 680 +- 5% SMT Resistor Array 4 Res 1206 | RA1 | 1206 RA | 680 +- 5% SMT Resistor Array 4 Res 1206 | 1
1k +- 5% SMT Resistor Array | 1k +- 5% SMT Resistor Array 4 Res | RA2 | 1206 RA | 1k +- 5% SMT Resistor Array | 1
Programming Headers Dual Row | Programming Headers Dual Row | S1 | ISP HEADER | Programming ISP, Programming Headers Dual Row | 1
Tac switch | small tac switch | sw1 | MY_PB-SMD | Tac switch_1 | 1
LM1117 | Low Drop Voltage Reg | U1 | MY_SOT223 | LM1117 | 1
FT232RL | USB Bridge, USB to UART USB 2.0 UART Interface 28-SSOP | U2 | SSOP-28-FT232RL | FT232RL | 1
ATMEGA328P-AU | ATmega48A/PA/88A/PA/168A/PA/328/P | U3 | TQFP80P900X900X120-32N | AtmelMicrocontroller | 1
Aker 16MHz Crystal SMT | Aker S5C SMT Crystal | X1 | Aker S5C Crystal | Aker C5S-16.000-12-3030-X | 1

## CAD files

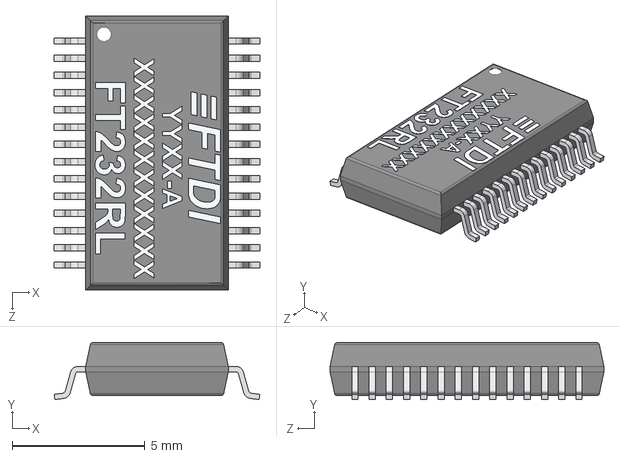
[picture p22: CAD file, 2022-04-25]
Özel Arduino Nano Tasarımı/StepDosyaları/User Library-SSOP-28-FT232RL.STEP
7.76 x 2.16 x 10.3 mm

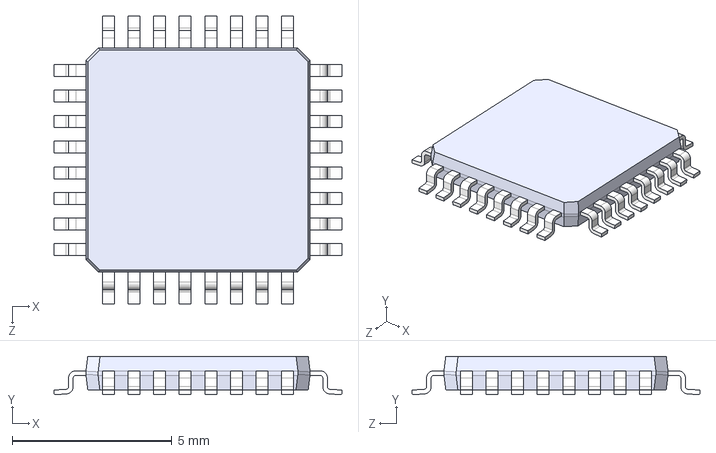
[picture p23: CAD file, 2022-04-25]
Özel Arduino Nano Tasarımı/StepDosyaları/ATMEGA328P-AU--3DModel-STEP-56544.STEP
9.00 x 1.20 x 9.00 mm

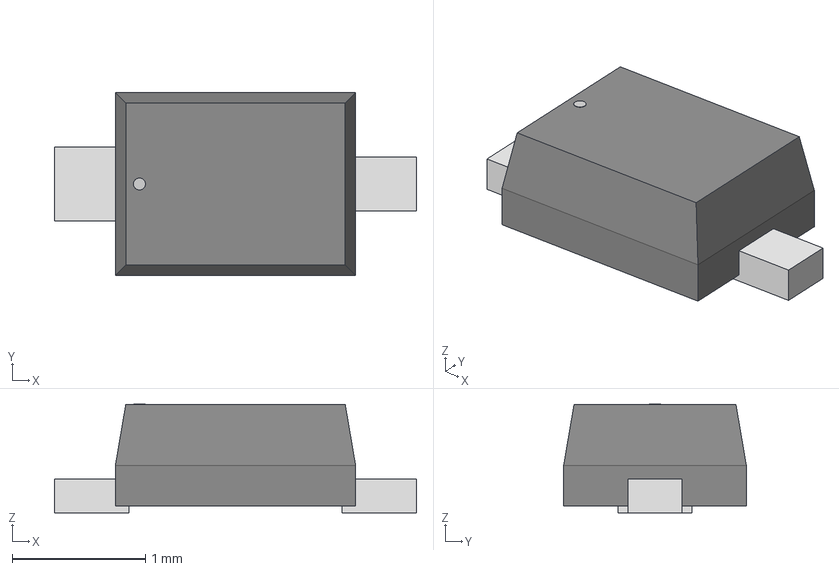
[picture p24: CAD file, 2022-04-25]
Özel Arduino Nano Tasarımı/StepDosyaları/SMINI2-F5-B_PAN.step
2.72 x 1.37 x 0.815 mm

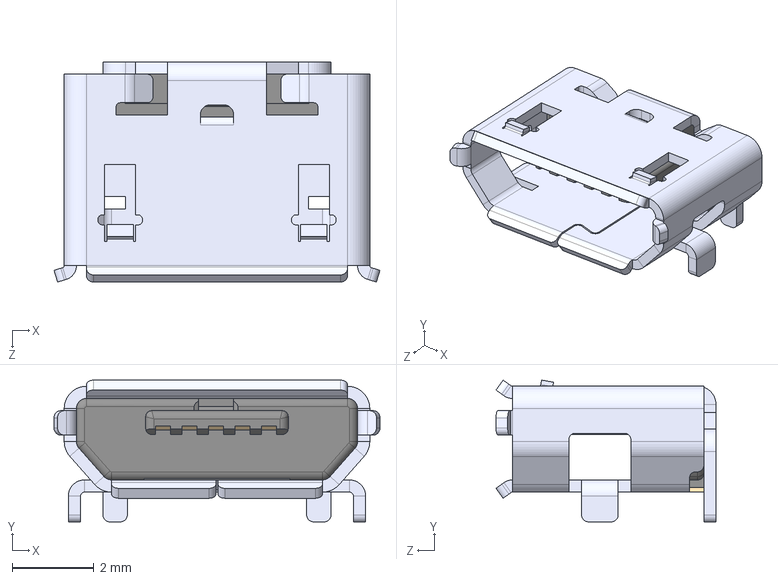
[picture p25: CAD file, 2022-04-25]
Özel Arduino Nano Tasarımı/StepDosyaları/1050170001--3DModel-STEP-56544.STEP
8.00 x 3.48 x 5.40 mm
